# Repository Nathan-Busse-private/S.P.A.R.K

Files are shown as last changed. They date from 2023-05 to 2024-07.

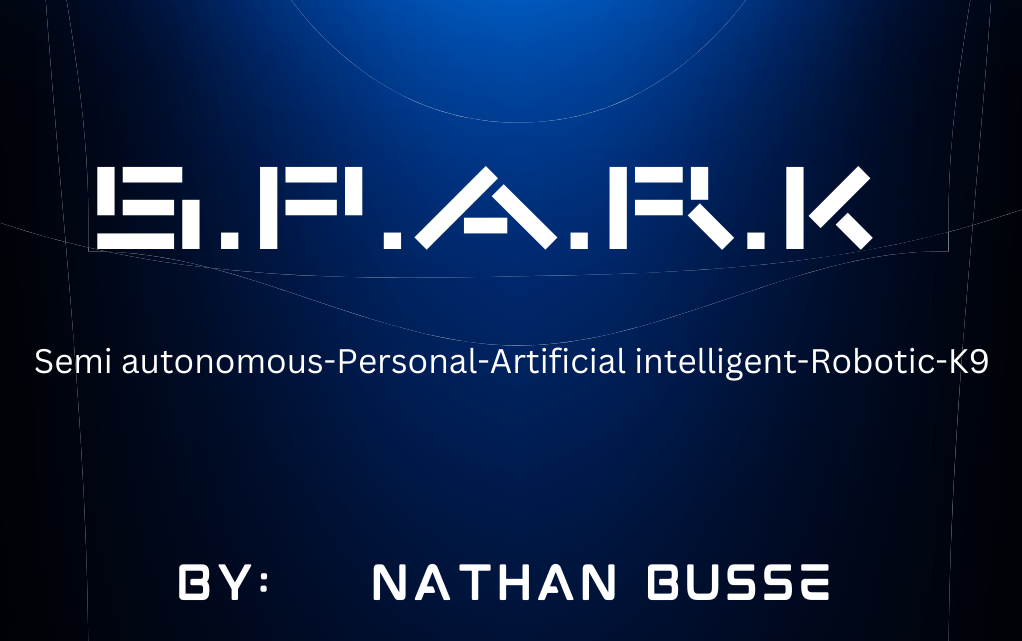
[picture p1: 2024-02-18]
Src/Dependencies/S.P.A.R.K.png

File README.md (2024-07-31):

 

A robot dog with a heart.

# TO DO:

Hardware
------------

- [x]  Redesign tibia joint.
- [x]  Redesign gyro mount.
- [x]  Replace UNO with Raspberry Pi 4B.
- [x]  Add Arduino NANO
- [x]  Add a 5.1 volt 3 amp regulator.
- [ ]  Replace gel battery with lithium ion.
- [ ]  Add web-cams.
- [ ]  Add GPS.
  
C++
------------

- [x]  Make S.P.A.R.K walk.
- [x]  Control S.P.A.R.K through bluetooth.
- [x]  Add killswitch function.
- [x]  Make Serial_slave script
- [x]  Make S.P.A.R.K rest.
- [x]  Make S.P.A.R.K pivot.
- [x]  Make S.P.A.R.K sit.
- [ ]  Replace delay function with millis.
- [ ]  Perfect walking gaits.
- [ ]  Create PID algorithm to adjust IK to help S.P.A.R.K naviagate uneven terrain better.
- [ ]  Implement PID algorithm.

Java
------------

- [x]  Redesign S.P.A.R.K logo.
- [x]  Build a disributable apk file for the app.
- [x]  Create a Build history directory for the app.
- [ ]  Implement S.P.A.R.K setup and configuration settings through the app.

Python
-----------

- [x]  Work on object detection.
- [x]  Work on body tracker.
- [x]  Work on hand tracker.
- [x]  Work on Serial_master script
- [x]  Work on Bluetooth_command script.
- [ ]  Work on DNN.
- [ ]  Work on Body behavior animations.
- [ ]  Implement cloud update protacol.
- [ ]  Implement auto cloud backup protacol.
- [ ]  Implement SSH communication protacol.
- [ ]  Recover from power loss.
- [ ]  Work on object avoidance engine.
- [ ]  Work on autonomous navigation engine.
- [ ]  Work on speech recognition engine.
- [ ]  Work on personality matrix.
- [ ]  Work on diagnostic and status communication to S.P.A.R.K app.
- [ ]  Work on GPS communication protacol.

Bash
-----------

- [x] Work on Blueman installer script
- [x] Work on Bluetooth installer script
- [x] Work on Arduino setup script
- [x] Work on Bluetooth initializer script 

# Known bugs:

Hardware
-----------

- [x] Femur A & C is not alligned with Femur B & D.

C++
-----------

- [x] Rest mode takes 4 seconds to engage once S.P.A.R.K has been powered on.
- [x] Tibia B lifts first instead D causing S.P.A.R.K to lose balance at the first stride but recover there after.
- [ ] In Bluetooth Nightly V2 S.P.A.R.K walks on the spot when commanding him to move forward.
- [ ] Tibia do not lift off the ground propperly causing S.P.A.R.K to be unable to step over carpats. 

Java
-----------

- [x]  App doesn't transmit stop command automatically after connection in the app.
- [ ]  Device falls asleep when no input is given in the app after the devices set sleep time is lapsed.

Python
-----------

Bash
-----------

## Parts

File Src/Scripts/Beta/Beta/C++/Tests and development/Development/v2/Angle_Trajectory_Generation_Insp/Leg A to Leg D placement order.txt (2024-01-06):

IKe'7 :
bUBBa ===won
ViR?„„„,
V't P v/'
+ : --TDIK4 qCq,{\tV\\
SV% brca\ WAl
LeVI &d.
V' fat\\
'tD lwAI
ftbx„\BI
’ FeW\v\?n
.etWv\ t
A
BATT tRY
le--tV+IB
b{–l'\N6vA t\
Le9 \
)p-5 V\q&C,\ IUv\,\
J
bcg A
YLQ'\,.d Pq'v\
} {9\$
A?
h
*a'
iF
.J{
.<
\r
uP
{-,
\\/
a
V
'n
\ Jn1
,/’
C
M\ 1 rl :’
JiL'' L–„–- VJ)
ITa p VIew’

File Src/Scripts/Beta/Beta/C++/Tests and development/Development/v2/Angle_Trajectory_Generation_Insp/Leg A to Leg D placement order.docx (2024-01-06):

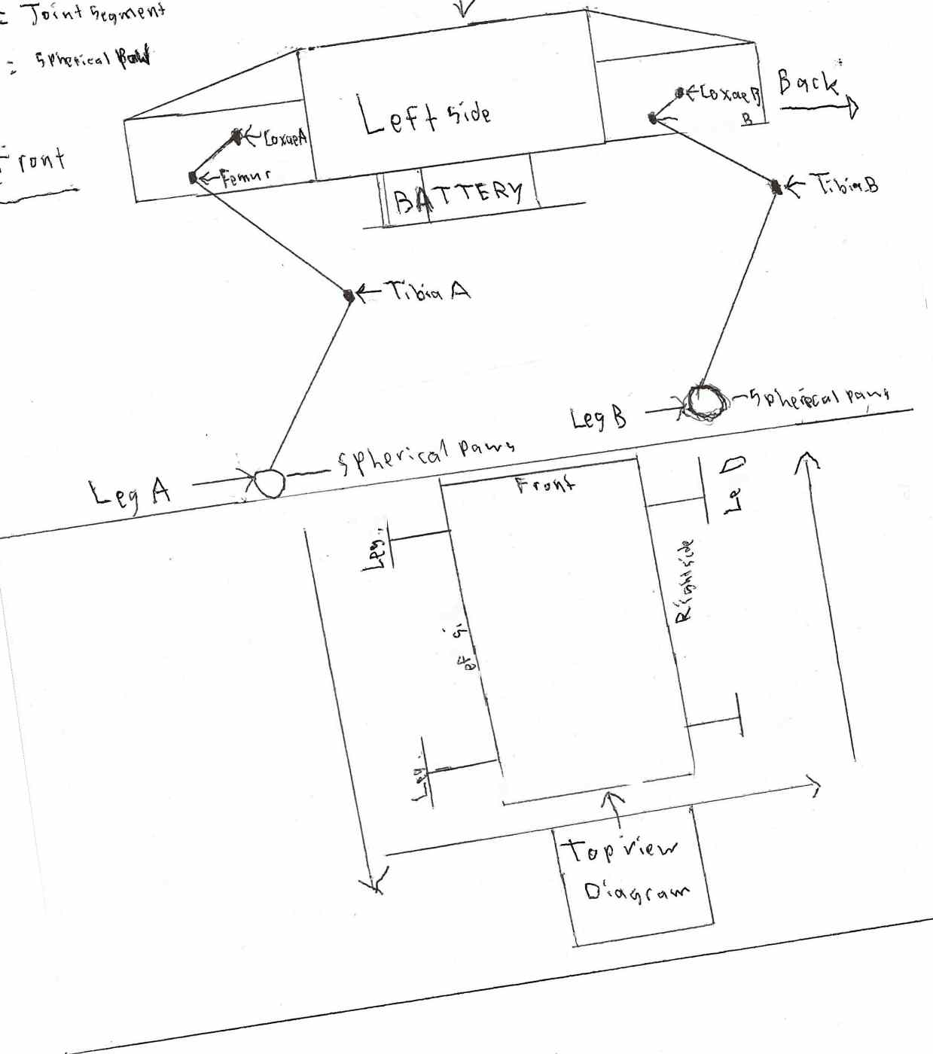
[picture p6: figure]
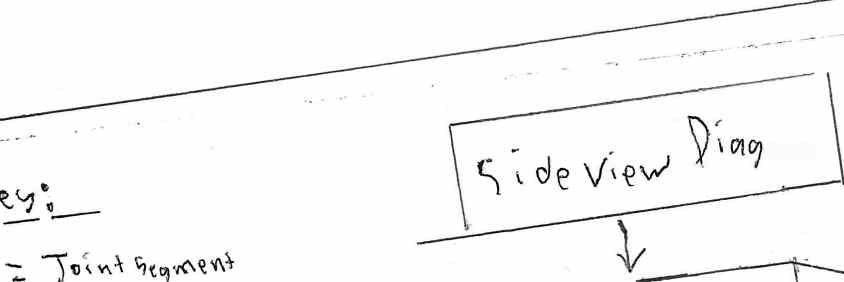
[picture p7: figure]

"Z' I

GP

'a

._J'

[ RW\

B.At

'W -

fI

C

UP

J

A

CS,\

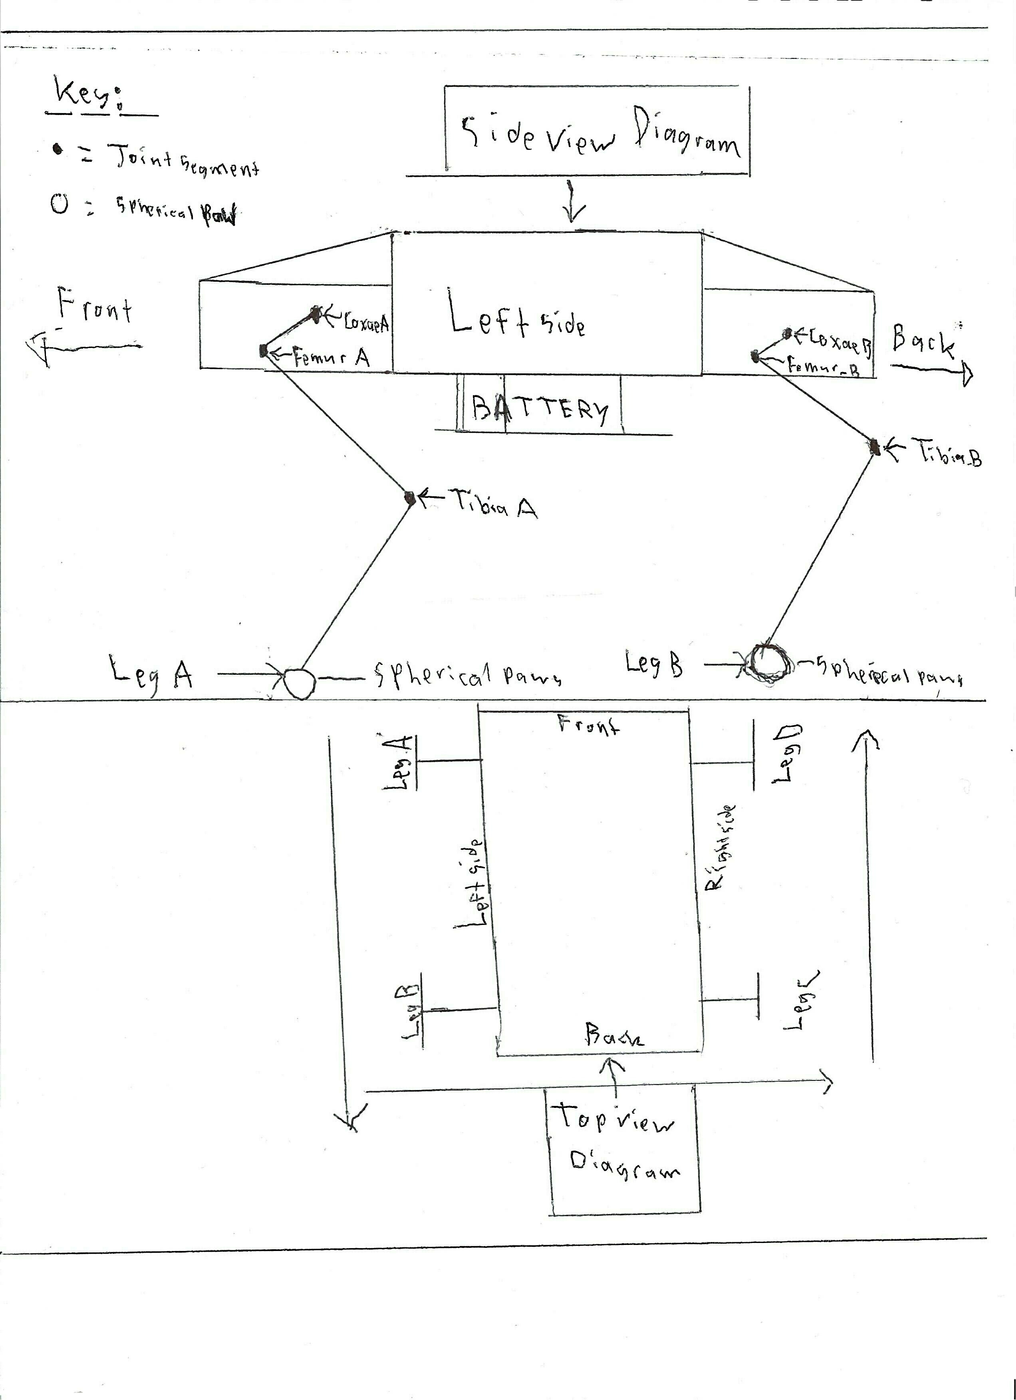
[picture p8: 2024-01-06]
Src/Scripts/Beta/Beta/C++/Tests and development/Development/v2/Angle_Trajectory_Generation_Insp/Leg A to Leg D placement order.jpg

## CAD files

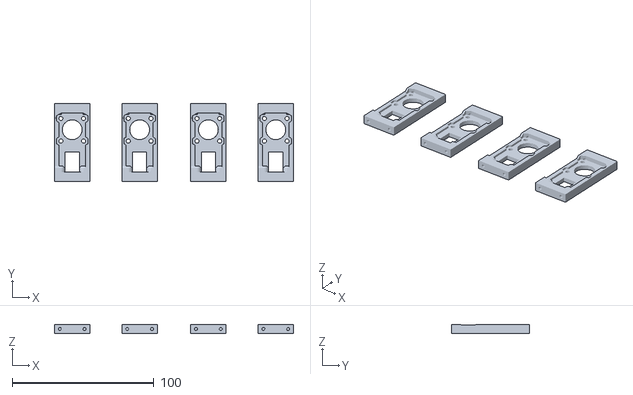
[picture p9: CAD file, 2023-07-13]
Src/Scripts/In-Dev/In-Dev/Models/Leg parts/Tibia/x1/Tibia joint main bracket v1.stl
168.5 x 55.2 x 6.00

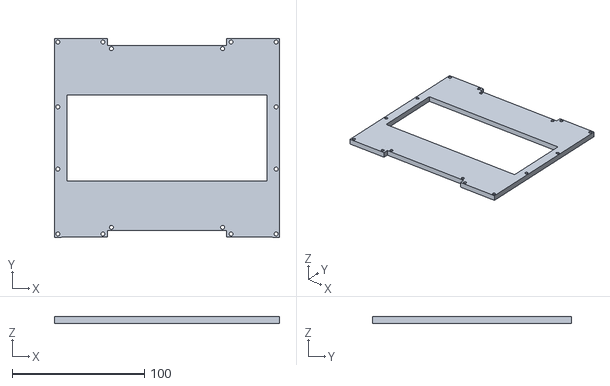
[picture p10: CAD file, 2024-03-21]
Src/Scripts/Alpha/Alpha/Models/Body parts/x1/Battery slot.stl
170.0 x 150.0 x 5.00

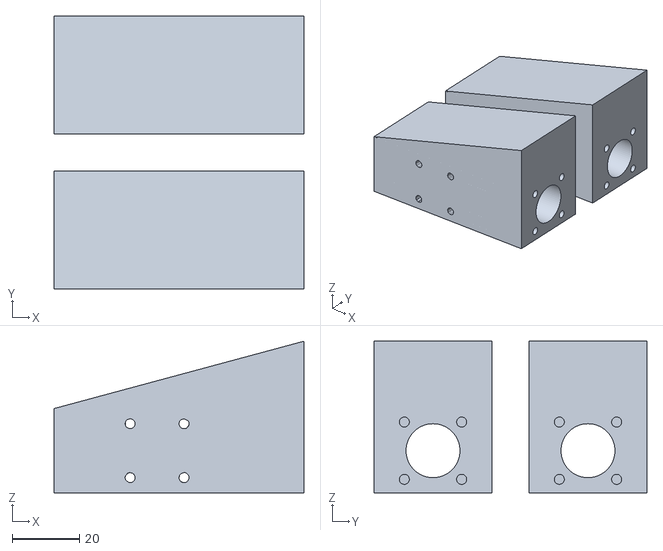
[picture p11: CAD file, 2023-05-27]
Src/Scripts/Alpha/Alpha/Models/Leg parts/Coxae/x2/Torsou 2.0.stl
74.2 x 81.0 x 45.0

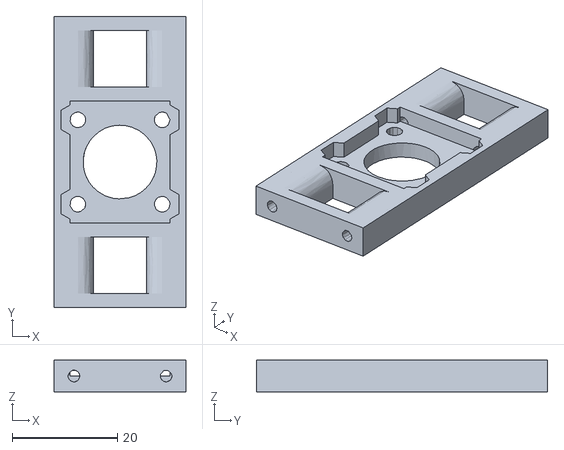
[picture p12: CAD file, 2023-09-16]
Src/Scripts/Alpha/Alpha/Models/Leg parts/Coxae/x4/Coxae joint bracket single.stl
25.0 x 55.2 x 6.00

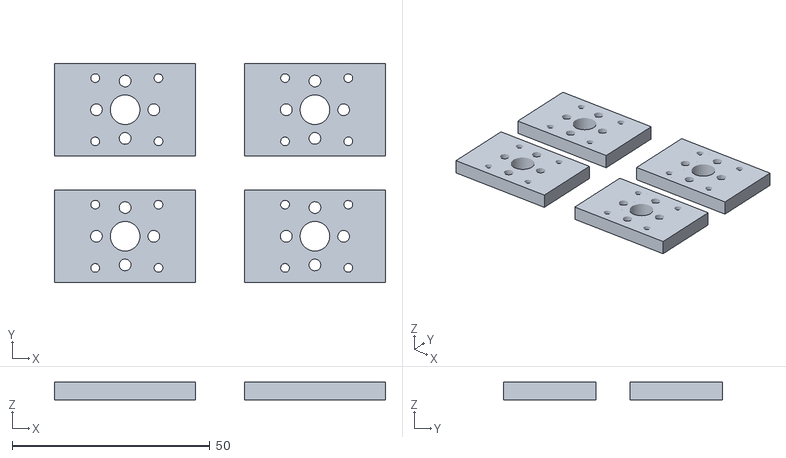
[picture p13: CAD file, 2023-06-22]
Src/Scripts/Alpha/Alpha/Models/Leg parts/Femur/x1/Femur joint v2.stl
83.7 x 55.3 x 4.50

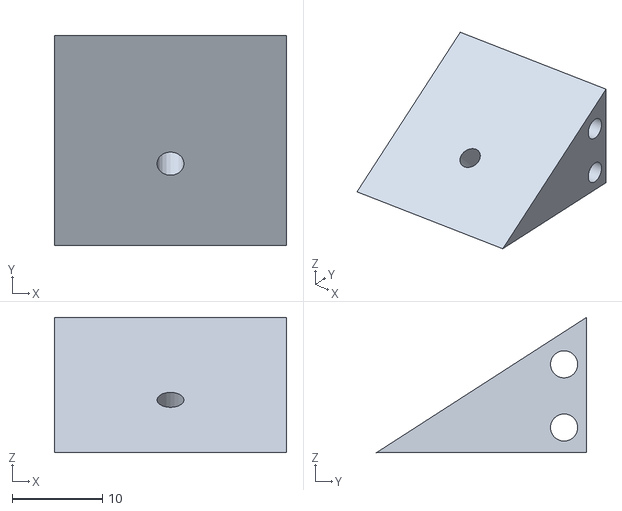
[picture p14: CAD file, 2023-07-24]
Src/Scripts/Alpha/Alpha/Models/Leg parts/Tibia/x1/Paw attachment bracket v4.stl
25.7 x 23.3 x 15.0

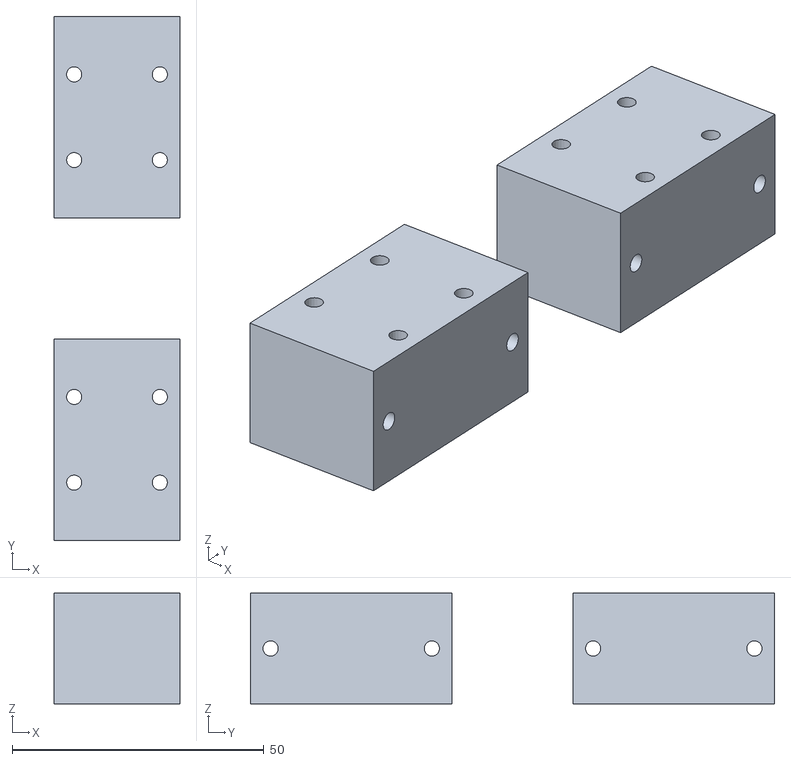
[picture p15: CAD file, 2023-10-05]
Src/Scripts/Alpha/Alpha/Nightly/Models/Body parts/x1/GoPro body attachment v2.stl
25.0 x 104.0 x 22.0

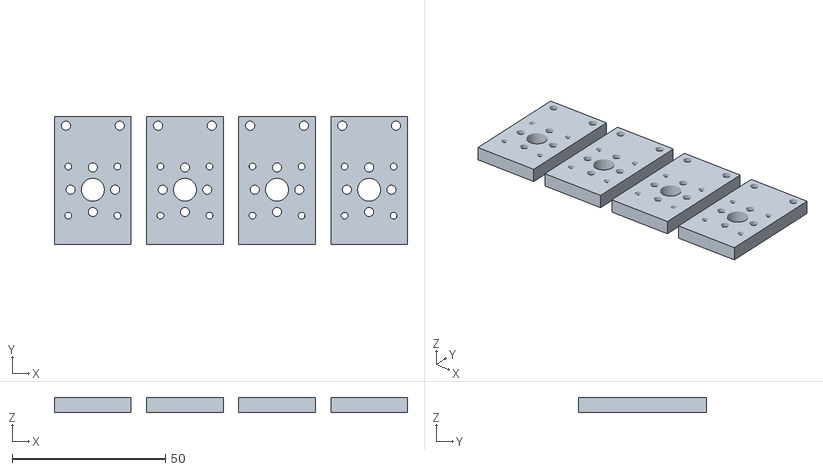
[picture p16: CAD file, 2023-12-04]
Src/Scripts/Alpha/Alpha/Nightly/Models/Leg parts/Coxae/x4/Femur secure bracket.stl
115.0 x 41.7 x 5.00

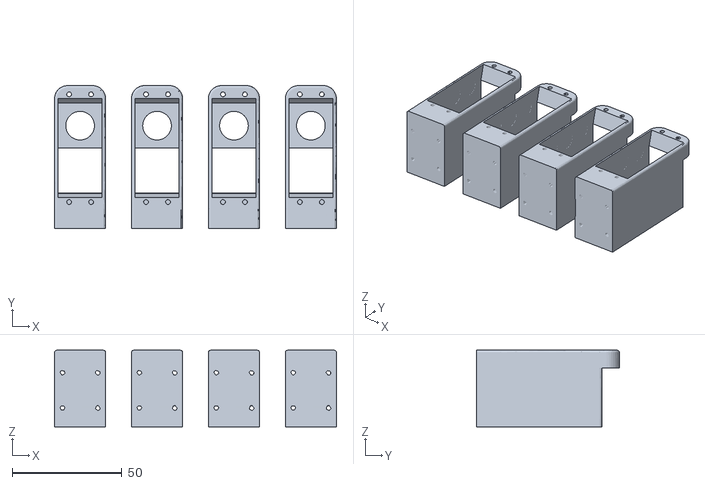
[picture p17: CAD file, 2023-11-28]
Src/Scripts/Alpha/Alpha/Nightly/Models/Leg parts/Femur/x1/Femur v3.stl
128.3 x 65.0 x 34.8

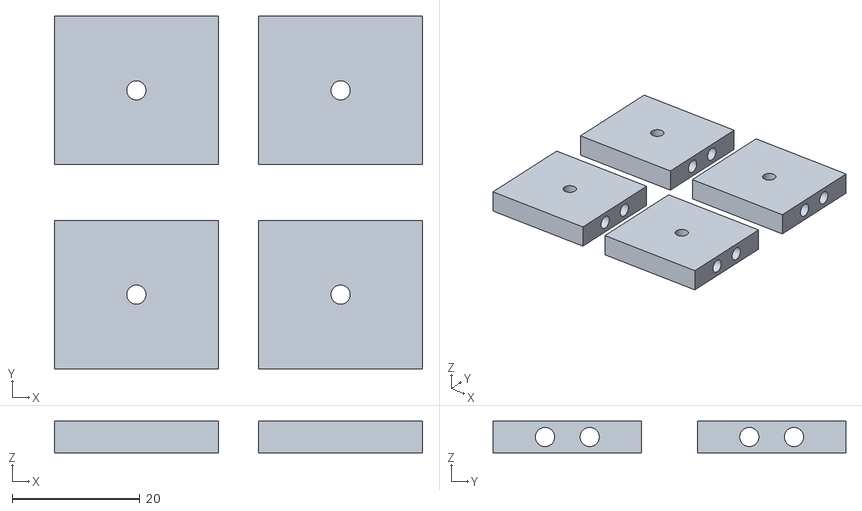
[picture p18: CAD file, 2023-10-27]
Src/Scripts/Alpha/Alpha/Nightly/Models/Leg parts/Redesign/Paw attachment bracket v4.stl
57.7 x 55.3 x 5.00

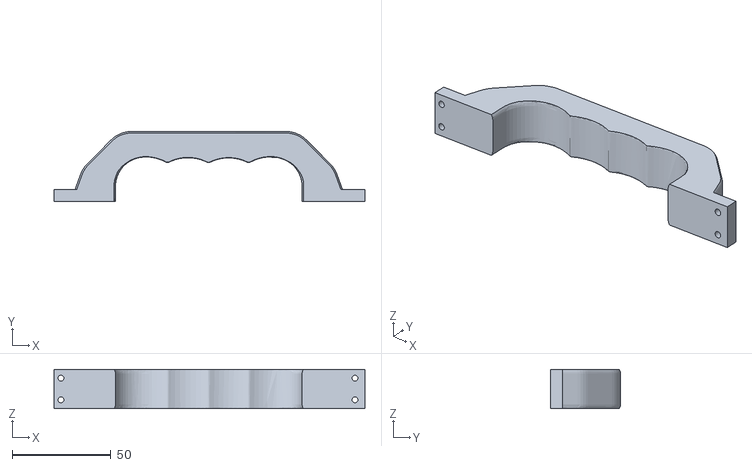
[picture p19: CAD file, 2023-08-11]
Src/Scripts/Alpha/Alpha/Stable/Models/Body parts/x1/Carry handle.stl
157.6 x 35.5 x 20.0

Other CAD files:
Src/Scripts/Alpha/Alpha/Models/Body parts/x1/30mm fan mount.stl
Src/Scripts/Alpha/Alpha/Models/Body parts/x1/Battery base panel.stl
Src/Scripts/Alpha/Alpha/Models/Body parts/x1/Battery side wall.stl
Src/Scripts/Alpha/Alpha/Models/Body parts/x1/Bottom plate v2.0.stl
Src/Scripts/Alpha/Alpha/Models/Body parts/x1/Chassis back.stl
Src/Scripts/Alpha/Alpha/Models/Body parts/x1/Chassis front.stl
Src/Scripts/Alpha/Alpha/Models/Body parts/x1/GoPro body attachment.stl
Src/Scripts/Alpha/Alpha/Models/Body parts/x1/GoPro bracket.stl
Src/Scripts/Alpha/Alpha/Models/Body parts/x1/Gyro mount.stl
Src/Scripts/Alpha/Alpha/Models/Body parts/x1/Side panel left 3.0.stl
Src/Scripts/Alpha/Alpha/Models/Body parts/x1/Side panel right 3.0.stl
Src/Scripts/Alpha/Alpha/Models/Body parts/x1/top.stl
Src/Scripts/Alpha/Alpha/Models/Leg parts/Coxae/x4/Coxae joint bracket.stl
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

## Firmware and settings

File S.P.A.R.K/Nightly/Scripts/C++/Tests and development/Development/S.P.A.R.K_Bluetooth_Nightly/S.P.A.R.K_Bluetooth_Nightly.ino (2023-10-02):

/* S.P.A.R.K_Bluetooth_Nightly
   Project: S.P.A.R.K
   Start date: 5 June 2023
   Last edited: 1 October 2023
   Info:

   Experimenting how to make S.P.A.R.K tibia_wait by manual control via Bluetooth.

   Made by Nathan-Busse
*/

//including the libraries
#include <SoftwareSerial.h>  // TX RX software library for bluetooth
#include <spark_pwm.h>
#include <Wire.h>

// Pin declarations
#define Coxae_A 0
#define Femur_A 1
#define Tibia_A 2

#define Coxae_B 4
#define Femur_B 5
#define Tibia_B 6

#define Coxae_C 8
#define Femur_C 9
#define Tibia_C 10

#define Coxae_D 12
#define Femur_D 13
#define Tibia_D 14

/* Coxae flat angle positions
   ---------------
*/
#define CL_idle 90
#define CR_idle 90

/* Resting leg position
   --------------------
*/

// Degres left femur
#define femur_l 180
#define tibia_l 0

// Degrees right femur
#define femur_r 0
#define tibia_r 180

/* Standing leg positions
   ----------------------
*/

// Left legs
#define FL_stand 135
#define TL_stand 65

// Right legs
#define FR_stand 45
#define TR_stand 115


/* Walking FORWARD leg positions
   -----------------------------
*/
// Left legs
#define FTL_rise 45
#define FFL_forward 130
#define FTL_lower 65
#define FFL_back 160

// Right legs
#define FTR_rise 135
#define FFR_forward 50
#define FTR_lower 115
#define FFR_back 20

/* Walking BACK leg positions
   --------------------------
*/
// Left legs
#define BTL_rise 45
#define BFL_forward 140
#define BTL_lower 65
#define BFL_back 160

// Right legs
#define BTR_rise 135
#define BFR_forward 50
#define BTR_lower 115
#define BFR_back 20

/* Walking LEFT leg positions
   --------------------------
*/

// Left legs
#define LTL_rise 45
#define LFL_forward 160  // 155
#define LTL_lower 65
#define LFL_back 130

// Right legs
#define LTR_rise 135
#define LFR_forward 45  // 45
#define LTR_lower 115
#define LFR_back 30

/* Walking RIGHT positions
   -----------------------
*/
// Left legs
#define RTL_rise 45
#define RFL_forward 134
#define RTL_lower 65
#define RFL_back 150

// Right legs
#define RTR_rise 135
#define RFR_forward 25
#define RTR_lower 115
#define RFR_back 46

/* Pivot left
-------------
*/
#define FCL0 70   // Coxae idle
#define FCR0 70   // Coxae idle
#define BCL0 110  // Coxae idle
#define BCR0 110  // Coxae idle

#define FCL10 74   // Coxae idle
#define FCR10 74   // Coxae idle
#define BCL10 106  // Coxae idle
#define BCR10 106  // Coxae idle

#define FCL20 78   // Coxae idle
#define FCR20 78   // Coxae idle
#define BCL20 102  // Coxae idle
#define BCR20 102  // Coxae idle

#define FCL30 82  // Coxae idle
#define FCR30 82  // Coxae idle
#define BCL30 98  // Coxae idle
#define BCR30 98  // Coxae idle

#define FCL40 86  // Coxae idle
#define FCR40 86  // Coxae idle
#define BCL40 94  // Coxae idle
#define BCR40 94  // Coxae idle

#define FCL50 90  // Coxae idle
#define FCR50 90  // Coxae idle
#define BCL50 90  // Coxae idle
#define BCR50 90  // Coxae idle

/* Pivot Right
-------------
*/
#define BCL60 86  // Coxae idle
#define BCR60 86  // Coxae idle
#define FCL60 94  // Coxae idle
#define FCR60 94  // Coxae idle

#define BCL70 82  // Coxae idle
#define BCR70 82  // Coxae idle
#define FCL70 98  // Coxae idle
#define FCR70 98  // Coxae idle

#define BCL80 78   // Coxae idle
#define BCR80 78   // Coxae idle
#define FCL80 102  // Coxae idle
#define FCR80 102  // Coxae idle

#define BCL90 74   // Coxae idle
#define BCR90 74   // Coxae idle
#define FCL90 106  // Coxae idle
#define FCR90 106  // Coxae idle

#define BCL100 70   // Coxae idle
#define BCR100 70   // Coxae idle
#define FCL100 110  // Coxae idle
#define FCR100 110  // Coxae idle

/* Time delay
   ----------
*/
#define stand 4
#define rest 4
#define femur_hold 300
#define tibia_hold 250
#define rotate 200
#define hold 400

/* PWM setup
   ---------
*/
#define MIN_PulseLength 500
#define MAX_PulseLength 2500
#define MED_PulseLength 2500
#define Frequency 50  // 50 HRz

spark_pwm pwm = spark_pwm();
int degrees;

//Initializing pins for bluetooth Module
int bluetoothTx = 10;  // bluetooth tx to 2 pin
int bluetoothRx = 11;  // bluetooth rx to 3 pin
SoftwareSerial bluetooth(bluetoothTx, bluetoothRx);

char command;  //variable to store the data

int previousMillisServo = 0;
int pos = 0;
long servoInterval = 400;
unsigned long currentMillis = 0;

void setup() {
  pwm.begin();
  pwm.setPWMFreq(Frequency);

  /* Resting position
   ----------------
*/

  // Left leg
  pwm.setPWM(Coxae_A, 0, pulseWidth(CL_idle));  // A
  pwm.setPWM(Femur_A, 0, pulseWidth(femur_l));  // A
  pwm.setPWM(Tibia_A, 0, pulseWidth(tibia_l));  // A

  pwm.setPWM(Coxae_B, 0, pulseWidth(CL_idle));  // B
  pwm.setPWM(Femur_B, 0, pulseWidth(femur_l));  // B
  pwm.setPWM(Tibia_B, 0, pulseWidth(tibia_l));  // B

  // Right leg
  pwm.setPWM(Coxae_C, 0, pulseWidth(CR_idle));  // C
  pwm.setPWM(Femur_C, 0, pulseWidth(femur_r));  // C
  pwm.setPWM(Tibia_C, 0, pulseWidth(tibia_r));  // C

  pwm.setPWM(Coxae_D, 0, pulseWidth(CR_idle));  // D
  pwm.setPWM(Femur_D, 0, pulseWidth(femur_r));  // D
  pwm.setPWM(Tibia_D, 0, pulseWidth(tibia_r));  // D
  delay(rest);

  Serial.begin(9600);
  bluetooth.begin(9600);
}

void loop() {
  if (bluetooth.available() > 0) {  //Checking if there is some data available or not
    command = bluetooth.read();     //Storing the data in the 'command' variable
    Serial.println(command);        //Printing it on the serial monitor

    //Change pin mode only if new command is different from previous.

    /* tibia_waiting commands
     ----------------------
  */

    currentMillis = millis();
    switch (command) {
      case 'F':  // Moving Forward
        forward();
        break;
      case 'B':  // Moving Backward
        back();

        break;
      case 'L':  // Moving Left
        left();

        break;
      case 'R':  // Moving Right
        right();

        break;
      case 'S':  // Stop
        stop();
        break;

      case 'Z':  // Sleep
        sleep();
        break;

        /*  Tricks
    ------
*/
      case 'W':  // Sit

        break;

      case 'U':  // Jump

        break;

      case 'J':  // Jog on the spot

        break;

      case '0':  // pivot 180 degrees
        pivot_pos_0();
        break;

      case '1':  // pivot 180 degrees
        pivot_pos_10();

        break;

      case '2':  // pivot 180 degrees
        pivot_pos_20();

        break;

      case '3':  // pivot 180 degrees
        pivot_pos_30();

        break;

      case '4':  // pivot 180 degrees
        pivot_pos_40();

        break;

      case '5':  // pivot 180 degrees
        pivot_pos_50();

        break;

      case '6':  // pivot 180 degrees
        pivot_pos_60();

        break;

      case '7':  // pivot 180 degrees
        pivot_pos_70();

        break;

      case '8':  // pivot 180 degrees
        pivot_pos_80();

        break;

      case '9':  // pivot 180 degrees
        pivot_pos_90();

        break;

      case 'q':  // pivot 180 degrees
        pivot_pos_100();

        break;

      case '~':  // pivot 180 degrees
        pivot_pos_50();

        break;

        /* EMERGENCY SHUTOFF
   -----------------
*/

      case 'E':  // Disable servos
        emergency_shutoff();
        break;
    }
  }
}

void stop() {

  /* Standing position
   ----------------
  */
  pwm.setPWM(Coxae_A, 0, pulseWidth(CL_idle));
  pwm.setPWM(Coxae_B, 0, pulseWidth(CL_idle));
  pwm.setPWM(Coxae_C, 0, pulseWidth(CR_idle));
  pwm.setPWM(Coxae_D, 0, pulseWidth(CR_idle));

  pwm.setPWM(Femur_A, 0, pulseWidth(FL_stand));
  pwm.setPWM(Femur_B, 0, pulseWidth(FL_stand));
  pwm.setPWM(Femur_C, 0, pulseWidth(FR_stand));
  pwm.setPWM(Femur_D, 0, pulseWidth(FR_stand));

  pwm.setPWM(Tibia_A, 0, pulseWidth(TL_stand));
  pwm.setPWM(Tibia_B, 0, pulseWidth(TL_stand));
  pwm.setPWM(Tibia_C, 0, pulseWidth(TR_stand));
  pwm.setPWM(Tibia_D, 0, pulseWidth(TR_stand));
}

void forward() {

  pwm.setPWM(Coxae_A, 0, pulseWidth(CL_idle));
  pwm.setPWM(Coxae_B, 0, pulseWidth(CL_idle));
  pwm.setPWM(Coxae_C, 0, pulseWidth(CR_idle));
  pwm.setPWM(Coxae_D, 0, pulseWidth(CR_idle));

  // Cycle 1
  // Back legs
  // Rise
  pwm.setPWM(Tibia_D, 0, pulseWidth(FTR_rise));
  pwm.setPWM(Tibia_B, 0, pulseWidth(FTL_rise));
  pwm.setPWM(Femur_D, 0, pulseWidth(FFR_forward));
  pwm.setPWM(Femur_B, 0, pulseWidth(FFL_forward));
  femur_wait();

  // Lower
  pwm.setPWM(Tibia_D, 0, pulseWidth(FTR_lower));
  pwm.setPWM(Tibia_B, 0, pulseWidth(FTL_lower));
  pwm.setPWM(Femur_D, 0, pulseWidth(FFR_back));
  pwm.setPWM(Femur_B, 0, pulseWidth(FFL_back));

  // Front legs
  // Rise
  pwm.setPWM(Tibia_A, 0, pulseWidth(FTL_rise));
  pwm.setPWM(Tibia_C, 0, pulseWidth(FTR_rise));
  pwm.setPWM(Femur_A, 0, pulseWidth(FFL_forward));
  pwm.setPWM(Femur_C, 0, pulseWidth(FFR_forward));
  tibia_wait();

  // Lower
  pwm.setPWM(Tibia_A, 0, pulseWidth(FTL_lower));
  pwm.setPWM(Tibia_C, 0, pulseWidth(FTR_lower));
  pwm.setPWM(Femur_A, 0, pulseWidth(FFL_back));
  pwm.setPWM(Femur_C, 0, pulseWidth(FFR_back));

  // Cycle 2
  // Back legs
  // Rise
  pwm.setPWM(Tibia_D, 0, pulseWidth(FTR_rise));
  pwm.setPWM(Tibia_B, 0, pulseWidth(FTL_rise));
  pwm.setPWM(Femur_D, 0, pulseWidth(FFR_forward));
  pwm.setPWM(Femur_B, 0, pulseWidth(FFL_forward));
  femur_wait();

  // Lower
  pwm.setPWM(Tibia_D, 0, pulseWidth(FTR_lower));
  pwm.setPWM(Tibia_B, 0, pulseWidth(FTL_lower));
  pwm.setPWM(Femur_D, 0, pulseWidth(FFR_back));
  pwm.setPWM(Femur_B, 0, pulseWidth(FFL_back));

  // Front legs
  // Rise
  pwm.setPWM(Tibia_A, 0, pulseWidth(FTL_rise));
  pwm.setPWM(Tibia_C, 0, pulseWidth(FTR_rise));
  pwm.setPWM(Femur_A, 0, pulseWidth(FFL_forward));
  pwm.setPWM(Femur_C, 0, pulseWidth(FFR_forward));
  tibia_wait();

  // Lower
  pwm.setPWM(Tibia_A, 0, pulseWidth(FTL_lower));
  pwm.setPWM(Tibia_C, 0, pulseWidth(FTR_lower));
  pwm.setPWM(Femur_A, 0, pulseWidth(FFL_back));
  pwm.setPWM(Femur_C, 0, pulseWidth(FFR_back));

  // Cycle 3
  // Back legs
  // Rise
  pwm.setPWM(Tibia_D, 0, pulseWidth(FTR_rise));
  pwm.setPWM(Tibia_B, 0, pulseWidth(FTL_rise));
  pwm.setPWM(Femur_D, 0, pulseWidth(FFR_forward));
  pwm.setPWM(Femur_B, 0, pulseWidth(FFL_forward));
  femur_wait();

  // Lower
  pwm.setPWM(Tibia_D, 0, pulseWidth(FTR_lower));
  pwm.setPWM(Tibia_B, 0, pulseWidth(FTL_lower));
  pwm.setPWM(Femur_D, 0, pulseWidth(FFR_back));
  pwm.setPWM(Femur_B, 0, pulseWidth(FFL_back));

  // Front legs
  // Rise
  pwm.setPWM(Tibia_A, 0, pulseWidth(FTL_rise));
  pwm.setPWM(Tibia_C, 0, pulseWidth(FTR_rise));
  pwm.setPWM(Femur_A, 0, pulseWidth(FFL_forward));
  pwm.setPWM(Femur_C, 0, pulseWidth(FFR_forward));
  tibia_wait();

  // Lower
  pwm.setPWM(Tibia_A, 0, pulseWidth(FTL_lower));
  pwm.setPWM(Tibia_C, 0, pulseWidth(FTR_lower));
  pwm.setPWM(Femur_A, 0, pulseWidth(FFL_back));
  pwm.setPWM(Femur_C, 0, pulseWidth(FFR_back));

  // Cycle 4
  // Back legs
  // Rise
  pwm.setPWM(Tibia_D, 0, pulseWidth(FTR_rise));
  pwm.setPWM(Tibia_B, 0, pulseWidth(FTL_rise));
  pwm.setPWM(Femur_D, 0, pulseWidth(FFR_forward));
  pwm.setPWM(Femur_B, 0, pulseWidth(FFL_forward));
  femur_wait();

  // Lower
  pwm.setPWM(Tibia_D, 0, pulseWidth(FTR_lower));
  pwm.setPWM(Tibia_B, 0, pulseWidth(FTL_lower));
  pwm.setPWM(Femur_D, 0, pulseWidth(FFR_back));
  pwm.setPWM(Femur_B, 0, pulseWidth(FFL_back));

  // Front legs
  // Rise
  pwm.setPWM(Tibia_A, 0, pulseWidth(FTL_rise));
  pwm.setPWM(Tibia_C, 0, pulseWidth(FTR_rise));
  pwm.setPWM(Femur_A, 0, pulseWidth(FFL_forward));
  pwm.setPWM(Femur_C, 0, pulseWidth(FFR_forward));
  tibia_wait();

  // Lower
  pwm.setPWM(Tibia_A, 0, pulseWidth(FTL_lower));
  pwm.setPWM(Tibia_C, 0, pulseWidth(FTR_lower));
  pwm.setPWM(Femur_A, 0, pulseWidth(FFL_back));
  pwm.setPWM(Femur_C, 0, pulseWidth(FFR_back));
}

void back() {

  pwm.setPWM(Coxae_A, 0, pulseWidth(CL_idle));
  pwm.setPWM(Coxae_B, 0, pulseWidth(CL_idle));
  pwm.setPWM(Coxae_C, 0, pulseWidth(CR_idle));
  pwm.setPWM(Coxae_D, 0, pulseWidth(CR_idle));

  // Cycle 1
  // Back legs
  // Rise
  pwm.setPWM(Tibia_D, 0, pulseWidth(BTR_rise));
  pwm.setPWM(Tibia_B, 0, pulseWidth(BTL_rise));
  pwm.setPWM(Femur_D, 0, pulseWidth(BFR_back));
  pwm.setPWM(Femur_B, 0, pulseWidth(BFL_back));
  femur_wait();

  // Lower
  pwm.setPWM(Tibia_D, 0, pulseWidth(BTR_lower));
  pwm.setPWM(Tibia_B, 0, pulseWidth(BTL_lower));
  pwm.setPWM(Femur_D, 0, pulseWidth(BFR_forward));
  pwm.setPWM(Femur_B, 0, pulseWidth(BFL_forward));

  // Front legs
  // Rise
  pwm.setPWM(Tibia_A, 0, pulseWidth(BTL_rise));
  pwm.setPWM(Tibia_C, 0, pulseWidth(BTR_rise));
  pwm.setPWM(Femur_A, 0, pulseWidth(BFL_back));
  pwm.setPWM(Femur_C, 0, pulseWidth(BFR_back));
  tibia_wait();

  // Lower
  pwm.setPWM(Tibia_A, 0, pulseWidth(BTL_lower));
  pwm.setPWM(Tibia_C, 0, pulseWidth(BTR_lower));
  pwm.setPWM(Femur_A, 0, pulseWidth(BFL_forward));
  pwm.setPWM(Femur_C, 0, pulseWidth(BFR_forward));

  // Cycle 2
  // Back legs
  // Rise
  pwm.setPWM(Tibia_D, 0, pulseWidth(BTR_rise));
  pwm.setPWM(Tibia_B, 0, pulseWidth(BTL_rise));
  pwm.setPWM(Femur_D, 0, pulseWidth(BFR_back));
  pwm.setPWM(Femur_B, 0, pulseWidth(BFL_back));
  femur_wait();

  // Lower
  pwm.setPWM(Tibia_D, 0, pulseWidth(BTR_lower));
  pwm.setPWM(Tibia_B, 0, pulseWidth(BTL_lower));
  pwm.setPWM(Femur_D, 0, pulseWidth(BFR_forward));
  pwm.setPWM(Femur_B, 0, pulseWidth(BFL_forward));

  // Front legs
  // Rise
  pwm.setPWM(Tibia_A, 0, pulseWidth(BTL_rise));
  pwm.setPWM(Tibia_C, 0, pulseWidth(BTR_rise));
  pwm.setPWM(Femur_A, 0, pulseWidth(BFL_back));
  pwm.setPWM(Femur_C, 0, pulseWidth(BFR_back));
  tibia_wait();

  // Lower
  pwm.setPWM(Tibia_A, 0, pulseWidth(BTL_lower));
  pwm.setPWM(Tibia_C, 0, pulseWidth(BTR_lower));
  pwm.setPWM(Femur_A, 0, pulseWidth(BFL_forward));
  pwm.setPWM(Femur_C, 0, pulseWidth(BFR_forward));

  // Cycle 3
  // Back legs
  // Rise
  pwm.setPWM(Tibia_D, 0, pulseWidth(BTR_rise));
  pwm.setPWM(Tibia_B, 0, pulseWidth(BTL_rise));
  pwm.setPWM(Femur_D, 0, pulseWidth(BFR_back));
  pwm.setPWM(Femur_B, 0, pulseWidth(BFL_back));
  femur_wait();

  // Lower
  pwm.setPWM(Tibia_D, 0, pulseWidth(BTR_lower));
  pwm.setPWM(Tibia_B, 0, pulseWidth(BTL_lower));
  pwm.setPWM(Femur_D, 0, pulseWidth(BFR_forward));
  pwm.setPWM(Femur_B, 0, pulseWidth(BFL_forward));

  // Front legs
  // Rise
  pwm.setPWM(Tibia_A, 0, pulseWidth(BTL_rise));
  pwm.setPWM(Tibia_C, 0, pulseWidth(BTR_rise));
  pwm.setPWM(Femur_A, 0, pulseWidth(BFL_back));
  pwm.setPWM(Femur_C, 0, pulseWidth(BFR_back));
  tibia_wait();

  // Lower
  pwm.setPWM(Tibia_A, 0, pulseWidth(BTL_lower));
  pwm.setPWM(Tibia_C, 0, pulseWidth(BTR_lower));
  pwm.setPWM(Femur_A, 0, pulseWidth(BFL_forward));
  pwm.setPWM(Femur_C, 0, pulseWidth(BFR_forward));

  // Cycle 4
  // Back legs
  // Rise
  pwm.setPWM(Tibia_D, 0, pulseWidth(BTR_rise));
  pwm.setPWM(Tibia_B, 0, pulseWidth(BTL_rise));
  pwm.setPWM(Femur_D, 0, pulseWidth(BFR_back));
  pwm.setPWM(Femur_B, 0, pulseWidth(BFL_back));
  femur_wait();

  // Lower
  pwm.setPWM(Tibia_D, 0, pulseWidth(BTR_lower));
  pwm.setPWM(Tibia_B, 0, pulseWidth(BTL_lower));
  pwm.setPWM(Femur_D, 0, pulseWidth(BFR_forward));
  pwm.setPWM(Femur_B, 0, pulseWidth(BFL_forward));

  // Front legs
  // Rise
  pwm.setPWM(Tibia_A, 0, pulseWidth(BTL_rise));
  pwm.setPWM(Tibia_C, 0, pulseWidth(BTR_rise));
  pwm.setPWM(Femur_A, 0, pulseWidth(BFL_back));
  pwm.setPWM(Femur_C, 0, pulseWidth(BFR_back));
  tibia_wait();

  // Lower
  pwm.setPWM(Tibia_A, 0, pulseWidth(BTL_lower));
  pwm.setPWM(Tibia_C, 0, pulseWidth(BTR_lower));
  pwm.setPWM(Femur_A, 0, pulseWidth(BFL_forward));
  pwm.setPWM(Femur_C, 0, pulseWidth(BFR_forward));
}

void left() {

  pwm.setPWM(Coxae_A, 0, pulseWidth(CL_idle));
  pwm.setPWM(Coxae_B, 0, pulseWidth(CL_idle));
  pwm.setPWM(Coxae_C, 0, pulseWidth(CR_idle));
  pwm.setPWM(Coxae_D, 0, pulseWidth(CR_idle));

  // Cycle 1
  // Rise
  pwm.setPWM(Tibia_A, 0, pulseWidth(LTL_rise));
  pwm.setPWM(Tibia_C, 0, pulseWidth(LTR_rise));
  pwm.setPWM(Femur_A, 0, pulseWidth(LFL_forward));
  pwm.setPWM(Femur_C, 0, pulseWidth(LFR_forward));
  turn();

  pwm.setPWM(Femur_D, 0, pulseWidth(LFR_forward));
  pwm.setPWM(Femur_B, 0, pulseWidth(LFL_forward));
  pwm.setPWM(Tibia_D, 0, pulseWidth(LTR_rise));
  pwm.setPWM(Tibia_B, 0, pulseWidth(LTL_rise));

  // Lower
  pwm.setPWM(Femur_A, 0, pulseWidth(LFL_back));
  pwm.setPWM(Femur_C, 0, pulseWidth(LFR_back));
  pwm.setPWM(Tibia_A, 0, pulseWidth(LTL_lower));
  pwm.setPWM(Tibia_C, 0, pulseWidth(LTR_lower));
  turn();

  pwm.setPWM(Femur_D, 0, pulseWidth(LFR_back));
  pwm.setPWM(Femur_B, 0, pulseWidth(LFL_back));
  pwm.setPWM(Tibia_D, 0, pulseWidth(LTR_lower));
  pwm.setPWM(Tibia_B, 0, pulseWidth(LTL_lower));

  // Cycle 2
  pwm.setPWM(Coxae_A, 0, pulseWidth(CL_idle));
  pwm.setPWM(Coxae_B, 0, pulseWidth(CL_idle));
  pwm.setPWM(Coxae_C, 0, pulseWidth(CR_idle));
  pwm.setPWM(Coxae_D, 0, pulseWidth(CR_idle));

  // Rise
  pwm.setPWM(Tibia_A, 0, pulseWidth(LTL_rise));
  pwm.setPWM(Tibia_C, 0, pulseWidth(LTR_rise));
  pwm.setPWM(Femur_A, 0, pulseWidth(LFL_forward));
  pwm.setPWM(Femur_C, 0, pulseWidth(LFR_forward));
  turn();

  pwm.setPWM(Femur_D, 0, pulseWidth(LFR_forward));
  pwm.setPWM(Femur_B, 0, pulseWidth(LFL_forward));
  pwm.setPWM(Tibia_D, 0, pulseWidth(LTR_rise));
  pwm.setPWM(Tibia_B, 0, pulseWidth(LTL_rise));

  // Lower
  pwm.setPWM(Femur_A, 0, pulseWidth(LFL_back));
  pwm.setPWM(Femur_C, 0, pulseWidth(LFR_back));
  pwm.setPWM(Tibia_A, 0, pulseWidth(LTL_lower));
  pwm.setPWM(Tibia_C, 0, pulseWidth(LTR_lower));
  turn();

  pwm.setPWM(Femur_D, 0, pulseWidth(LFR_back));
  pwm.setPWM(Femur_B, 0, pulseWidth(LFL_back));
  pwm.setPWM(Tibia_D, 0, pulseWidth(LTR_lower));
  pwm.setPWM(Tibia_B, 0, pulseWidth(LTL_lower));

  // Cycle 3
  pwm.setPWM(Coxae_A, 0, pulseWidth(CL_idle));
  pwm.setPWM(Coxae_B, 0, pulseWidth(CL_idle));
  pwm.setPWM(Coxae_C, 0, pulseWidth(CR_idle));
  pwm.setPWM(Coxae_D, 0, pulseWidth(CR_idle));

  // Rise
  pwm.setPWM(Tibia_A, 0, pulseWidth(LTL_rise));
  pwm.setPWM(Tibia_C, 0, pulseWidth(LTR_rise));
  pwm.setPWM(Femur_A, 0, pulseWidth(LFL_forward));
  pwm.setPWM(Femur_C, 0, pulseWidth(LFR_forward));
  turn();

  pwm.setPWM(Femur_D, 0, pulseWidth(LFR_forward));
  pwm.setPWM(Femur_B, 0, pulseWidth(LFL_forward));
  pwm.setPWM(Tibia_D, 0, pulseWidth(LTR_rise));
  pwm.setPWM(Tibia_B, 0, pulseWidth(LTL_rise));

  // Lower
  pwm.setPWM(Femur_A, 0, pulseWidth(LFL_back));
  pwm.setPWM(Femur_C, 0, pulseWidth(LFR_back));
  pwm.setPWM(Tibia_A, 0, pulseWidth(LTL_lower));
  pwm.setPWM(Tibia_C, 0, pulseWidth(LTR_lower));
  turn();

  pwm.setPWM(Femur_D, 0, pulseWidth(LFR_back));
  pwm.setPWM(Femur_B, 0, pulseWidth(LFL_back));
  pwm.setPWM(Tibia_D, 0, pulseWidth(LTR_lower));
  pwm.setPWM(Tibia_B, 0, pulseWidth(LTL_lower));

  // Cycle 4
  pwm.setPWM(Coxae_A, 0, pulseWidth(CL_idle));
  pwm.setPWM(Coxae_B, 0, pulseWidth(CL_idle));
  pwm.setPWM(Coxae_C, 0, pulseWidth(CR_idle));
  pwm.setPWM(Coxae_D, 0, pulseWidth(CR_idle));

  // Rise
  pwm.setPWM(Tibia_A, 0, pulseWidth(LTL_rise));
  pwm.setPWM(Tibia_C, 0, pulseWidth(LTR_rise));
  pwm.setPWM(Femur_A, 0, pulseWidth(LFL_forward));
  pwm.setPWM(Femur_C, 0, pulseWidth(LFR_forward));
  turn();

  pwm.setPWM(Femur_D, 0, pulseWidth(LFR_forward));
  pwm.setPWM(Femur_B, 0, pulseWidth(LFL_forward));
  pwm.setPWM(Tibia_D, 0, pulseWidth(LTR_rise));
  pwm.setPWM(Tibia_B, 0, pulseWidth(LTL_rise));

  // Lower
  pwm.setPWM(Femur_A, 0, pulseWidth(LFL_back));
  pwm.setPWM(Femur_C, 0, pulseWidth(LFR_back));
  pwm.setPWM(Tibia_A, 0, pulseWidth(LTL_lower));
  pwm.setPWM(Tibia_C, 0, pulseWidth(LTR_lower));
  turn();

  pwm.setPWM(Femur_D, 0, pulseWidth(LFR_back));
  pwm.setPWM(Femur_B, 0, pulseWidth(LFL_back));
  pwm.setPWM(Tibia_D, 0, pulseWidth(LTR_lower));
  pwm.setPWM(Tibia_B, 0, pulseWidth(LTL_lower));
}
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

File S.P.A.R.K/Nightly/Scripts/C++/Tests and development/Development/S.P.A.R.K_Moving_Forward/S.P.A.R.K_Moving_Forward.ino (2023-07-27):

/* S.P.A.R.K moving forward
   Project: S.P.A.R.K
   Start date: 31 May 2023
   Last edited: 13 June 2023
   Info:

  My attempt to make S.P.A.R.K walk forward for the first time.

  My walking theory:
  ------------------
  Their will be 2 legs touching the ground and 2 in the air for each step.
  The 2 legs will operate in sync with the other leg diagnal from its partner.
  For example:

  Leg A will partner with Leg C
  Leg B will partner with Leg D.

  The Tibia of the paired legs will lift first and the Femur will then lift second. 
  Once the second pair of legs begin to lift, the already raised Femur will then lower
  first then the Tibia will lower second which follows on indefinitly, thus making the robot walk.

  Made by Nathan-Busse.
*/

// Calling Libraries
#include <Adafruit_PWMServoDriver.h>
#include <Wire.h>

// Pin declarations
#define Coxae_A 0
#define Femur_A 1
#define Tibia_A 2

#define Coxae_B 4
#define Femur_B 5
#define Tibia_B 6

#define Coxae_C 8
#define Femur_C 9
#define Tibia_C 10

#define Coxae_D 12
#define Femur_D 13
#define Tibia_D 14

/* Coxae positions
   ---------------
*/
#define CL_idle 90
#define CR_idle 90

/* Resting leg position
   --------------------
*/

// Degres left femur
#define coxae_l 90
#define femur_l 180
#define tibia_l 0

// Degrees right femur
#define coxae_r 90
#define femur_r 0
#define tibia_r 0


/* Standing leg positions
   ----------------------
*/

// Left legs
#define FL_stand 135
#define TL_stand 70

// Right legs
#define FR_stand 45
#define TR_stand 70


/* Walking leg positions
   ---------------------
*/

// Left legs
#define TL_rise 35
#define FL_forward 130
#define TL_lower 45
#define FL_back 160

// Right legs
#define TR_rise 35
#define FR_forward 50
#define TR_lower 45
#define FR_back 20




/* Time delay
   ----------
*/
#define stand 4000
#define hold 400
#define rest 4000

/* PWM setup
   ---------
*/
#define MIN_PulseLength 500
#define MAX_PulseLength 2500
#define MED_PulseLength 2500
#define Frequency 50  // 50 HRz

Adafruit_PWMServoDriver pwm = Adafruit_PWMServoDriver();
int degrees;

void setup() {
  pwm.begin();
  pwm.setPWMFreq(Frequency);

/* Resting position
   ----------------
*/

// Left leg
  pwm.setPWM(Coxae_A, 0, pulseWidth(coxae_l));  // A
  pwm.setPWM(Femur_A, 0, pulseWidth(femur_l));  // A
  pwm.setPWM(Tibia_A, 0, pulseWidth(tibia_l));  // A

  pwm.setPWM(Coxae_B, 0, pulseWidth(coxae_l));   // B
  pwm.setPWM(Femur_B, 0, pulseWidth(femur_l));  // B
  pwm.setPWM(Tibia_B, 0, pulseWidth(tibia_l));  // B

  // Right leg
  pwm.setPWM(Coxae_C, 0, pulseWidth(coxae_r));   // C
  pwm.setPWM(Femur_C, 0, pulseWidth(femur_r));  // C
  pwm.setPWM(Tibia_C, 0, pulseWidth(tibia_r));  // C

  pwm.setPWM(Coxae_D, 0, pulseWidth(coxae_r));   // D
  pwm.setPWM(Femur_D, 0, pulseWidth(femur_r));  // D
  pwm.setPWM(Tibia_D, 0, pulseWidth(tibia_r));  // D

  // Left leg
  pwm.setPWM(Coxae_A, 0, pulseWidth(coxae_l));  // A
  pwm.setPWM(Femur_A, 0, pulseWidth(femur_l));  // A
  pwm.setPWM(Tibia_A, 0, pulseWidth(tibia_l));  // A

  pwm.setPWM(Coxae_B, 0, pulseWidth(coxae_l));   // B
  pwm.setPWM(Femur_B, 0, pulseWidth(femur_l));  // B
  pwm.setPWM(Tibia_B, 0, pulseWidth(tibia_l));  // B

  // Right leg
  pwm.setPWM(Coxae_C, 0, pulseWidth(coxae_r));   // C
  pwm.setPWM(Femur_C, 0, pulseWidth(femur_r));  // C
  pwm.setPWM(Tibia_C, 0, pulseWidth(tibia_r));  // C

  pwm.setPWM(Coxae_D, 0, pulseWidth(coxae_r));   // D
  pwm.setPWM(Femur_D, 0, pulseWidth(femur_r));  // D
  pwm.setPWM(Tibia_D, 0, pulseWidth(tibia_r));  // D
  delay(rest);

  /* Standing position
   ----------------
  */
  pwm.setPWM(Coxae_A, 0, pulseWidth(CL_idle));
  pwm.setPWM(Coxae_B, 0, pulseWidth(CL_idle));
  pwm.setPWM(Coxae_C, 0, pulseWidth(CR_idle));
  pwm.setPWM(Coxae_D, 0, pulseWidth(CR_idle));

  pwm.setPWM(Femur_A, 0, pulseWidth(FL_stand));
  pwm.setPWM(Femur_B, 0, pulseWidth(FL_stand));
  pwm.setPWM(Femur_C, 0, pulseWidth(FR_stand));
  pwm.setPWM(Femur_D, 0, pulseWidth(FR_stand));

  pwm.setPWM(Tibia_A, 0, pulseWidth(TL_stand));
  pwm.setPWM(Tibia_B, 0, pulseWidth(TL_stand));
  pwm.setPWM(Tibia_C, 0, pulseWidth(TR_stand));
  pwm.setPWM(Tibia_D, 0, pulseWidth(TR_stand));
  delay(stand);
}

void loop() {

  // Walking
  pwm.setPWM(Coxae_A, 0, pulseWidth(CL_idle));
  pwm.setPWM(Coxae_B, 0, pulseWidth(CL_idle));
  pwm.setPWM(Coxae_C, 0, pulseWidth(CR_idle));
  pwm.setPWM(Coxae_D, 0, pulseWidth(CR_idle));


// Back legs
  // Rise
  pwm.setPWM(Tibia_D, 0, pulseWidth(TR_rise));
  pwm.setPWM(Tibia_B, 0, pulseWidth(TL_rise));
  pwm.setPWM(Femur_D, 0, pulseWidth(FR_forward));
  pwm.setPWM(Femur_B, 0, pulseWidth(FL_forward));
  delay(hold);

  // Lower
  pwm.setPWM(Tibia_D, 0, pulseWidth(TR_lower));
  pwm.setPWM(Tibia_B, 0, pulseWidth(TL_lower));
  pwm.setPWM(Femur_D, 0, pulseWidth(FR_back));
  pwm.setPWM(Femur_B, 0, pulseWidth(FL_back));

// Front legs
  // Rise
  pwm.setPWM(Tibia_A, 0, pulseWidth(TL_rise));
  pwm.setPWM(Tibia_C, 0, pulseWidth(TR_rise));
  pwm.setPWM(Femur_A, 0, pulseWidth(FL_forward));
  pwm.setPWM(Femur_C, 0, pulseWidth(FR_forward));
  delay(hold);

  // Lower
  pwm.setPWM(Tibia_A, 0, pulseWidth(TL_lower));
  pwm.setPWM(Tibia_C, 0, pulseWidth(TR_lower));
  pwm.setPWM(Femur_A, 0, pulseWidth(FL_back));
  pwm.setPWM(Femur_C, 0, pulseWidth(FR_back));
  delay(hold);
}

/* Pulsewidth declaration
   ----------------------
*/
int pulseWidth(int angle) {
  int pulse_wide, analog_value;
  pulse_wide = map(angle, 0, 180, MIN_PulseLength, MAX_PulseLength);
  analog_value = int(float(pulse_wide) / 1000000 * Frequency * 4096);
  Serial.println(analog_value);
  return analog_value;
}

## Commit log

2023-05-03 update
    Completed SPARK_servo_config.py.
    [LEGS v2.0.stl, Smooth tibia side panels.stl, Tibia parts.stl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]
2023-05-26 update
    Modified the torsou model and began modelling S.P.A.R.K's body.
    [Chassis back.stl, Chassis front.stl, Side panel left.stl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]
2023-05-30 update
    Added 3D model of bottom plate of body and modified side panel models. He is starting to take shape.
    [Bottom plate.stl]
2023-05-31 update
    S.P.A.R.K begins to walk
    [Tibia reprint.stl]
2023-06-01 update
    Modified the leg design because of a calculation error for the total weight must be.
    [Extender attachment bracket.stl, Extender side plate.stl, Femur joint.stl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]
2023-06-05 update
    Bug fixes and adding a new script to the S.P.A.R.K's library.
    [S.P.A.R.K_push_ups.ino, Servo_config_for_SPARK.ino]
2023-06-07 update
    modified bottom plate.
    [Bottom plate v2.0.stl, Bottom plate.stl]
2023-06-08 Hardware update
    Got a 6v 5A battery to test.
    My fingers are crossed.
2023-06-11 Software update
    Did some troubleshooting for walking issue.
    [S.P.A.R.K_Moving_Forward.ino, S.P.A.R.K_walking_troubleshoot.ino]
2023-06-11 Hardware update
    Added a new battery mount part.
    [Battery mount.stl]
2023-06-12 Bluetooth update
    Introducing millis() into the code
2023-06-13 update
    S.P.A.R.K can now walk in all directions.
    [Battery top.stl]
2023-06-16 Bluetooth update
    Working on millis().
2023-06-17 Hardware update
    Made GoPro mounts.
    [GoPro body attachment.stl, GoPro bracket.stl]
2023-06-19 Hardware update
    Modified battery mount model.
    [Battery mount v2.stl, Battery mount.stl]
2023-06-20 Bluetooth update
    Made some adjustments to the leg positions and commented out the millis function. Just don't why it won't work.
    You know what they say, "If you don't succeed try and try again.
    [S.P.A.R.K_Bluetooth.ino]
2023-06-22 Hardware update
    Fixed a design flaw in the Femur joint model.
    [Femur joint v2.stl, Femur joint.stl]
2023-06-27 Bluetooth update
    Made some improvements to the app and changed some of the sit button design.
2023-07-13 Hardware update
    Redesigned the Tibia joint and Paw based on the result data collected at Dikhololo.
    [Battery top.stl, Paw attachment bracket v2.stl, Paw attachment bracket v3.stl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]
2023-07-24 App and Hardware update
    Patched stop command not sent upon connection (v0.2).
    Moved battery to bottom.
    Replaced UNO with Raspberry Pi and is currently operated by a NANO.
    Battery cage has been redesigned and now fits.
    Redesigned Gyro mount.
    Redesigned Paw attachment bracket.
    [Battery base panel.stl, Battery mount v2.stl, Battery side wall.stl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]
2023-08-11 Super update
    [30mm fan mount.stl, Carry handle.stl, top.stl]
2023-09-09 Hierarchy update
    Reorganized folder structure.
    [30mm fan mount.stl, Battery base panel v2.0.stl, Battery base panel.stl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]
2023-09-16 Patch_update
    Redesigned Coxae joint and patched some bugs.
    [Battery base panel v3.0.stl, Coxae joint bracket single.stl, Coxae joint bracket.stl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]
2023-09-23 Bluetooth update
    Bug fixes.
    [S.P.A.R.K_Bluetooth_Nightly.ino]
2023-09-30 Library update
    Made a custom pwm library called spark_pwm to replace Adafruit's one.
    Patched femur A & C alignment issue.
    [S.P.A.R.K_Bluetooth_Nightly.ino]
2023-10-01 Bluetooth update
    Bug fixes
    [S.P.A.R.K_Bluetooth_Nightly.ino]
2023-10-05 Performance Update
    Redesigning walking algorithm in V2 folder.
    [GoPro body attachment v2.stl]
2023-10-08 Bluetooth Update
    Improved walking forward gate but found a bug that makes it walk like a frog. Not sure if it is hardware or software.
    [S.P.A.R.K_Bluetooth_Nightly.ino]
2023-10-14 Bluetooth Update
    Made S.P.A.R.K enter rest mode first before standing after terminating sit mode so that the servo motors are not put under stress.
2023-10-15 Bug Report
    In Bluetooth Nightly V2 S.P.A.R.K walks on the spot when commanding him to move forward.
    To diagnose the problem I am making v3 of the Bluetooth script from scratch and see what is causing the problem.
    [Forward_Nightly_v3.ino]
2023-10-15 Repository Update
    Broke the repo.
    [30mm fan mount.stl, Battery base panel v2.0.stl, Battery base panel v3.0.stl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]
2023-10-20 Hardware Update
    [Coxae V2.stl, Coxae v2.stl, Femur v2.stl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]
2023-10-25 Leg_Design_v4
    Redesigned S.P.A.R.K's legs.
    [Horn.stl, Leg Joint bearing v2.stl, Leg Joint horn v2.stl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]
2023-11-21 Hardware Update
    Upgraded S.P.A.R.K with more powerful servos.
2023-11-28 Hardware Update
    Made some improvements to the models.
    [Femur secure bracket.stl, Femur secure panel.stl, Femur v3.stl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]
2023-12-06 Hardware Update
    Redesigned the Femur attachment bracket to utilize the bearing used in the Femur model.
2024-02-18 BETA Update
    Felt like making a book to record my progress better.
    [30mm fan mount.stl, Battery base panel v2.0.stl, Battery base panel v3.0.stl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]
2024-02-18 S.P.A.R.K progress tracker book
    Felt like making a book to record my progress with S.P.A.R.K.
    This book will help ne find improvements as well as help me track any track down the problem causing the bug more efficiently while debugging or troubleshooting. problems with the robot.
2024-02-18 S.P.A.R.K progress tracker book
    S.P.A.R.K progress tracker book
    This book will act as a guide to optimize debugging.
    This book will help me spot any flaws and create the correct solutions for improvements.
    This book will optimize debug sessions, which will help me track down the source of the problem that is causing the bug more efficiently while debugging or troubleshooting. problems with the robot, hence optimizing debugging.
    An optimized debugging session will save me time and money.
    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
2024-03-03 Model Beta Update
    Redesigned the top plate 3D Model so that a 12.8 volt 7 Amp LiFePO4 SECURI-PROD Battery can slot inside the robot.
